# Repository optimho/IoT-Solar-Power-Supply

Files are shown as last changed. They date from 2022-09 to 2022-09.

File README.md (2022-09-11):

# IoT-Solar-Power-Supply
A small but highly efficient Solar power supply for electronics 

The repo consists of eagle cad files and a zip file with fabrication ready gerber files.

The power supply will charge a Lithium Ion 18650 battery and supply up to 4.1-3.0v 1A.
The battery voltage is monitored so that it will not run the battery flat and protect the battery. 

There is no short circuit protection on the device, so consider a 5v 1.5A fuse if you think that it is necssary.

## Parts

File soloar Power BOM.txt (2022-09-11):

Partlist exported from /home/michael/EAGLE/projects/Solar Power Supply/soloar Power.sch at 11/09/22 3:00 PM

Part Value                          Device                    Package              Description                                                   AVAILABILITY CATEGORY   CREATED_BY    DESCRIPTION                                DIGIKEY_PART_NUMBER DRAIN_CURRENT MANUFACTURER                     MF             MP               MPN               OC_FARNELL OC_NEWARK OPERATING_TEMP OPERATING_TEMPERATURE PACKAGE                PART_STATUS POPULARITY PRICE PROD_ID    PURCHASE-URL                                                      ROHS_COMPLIANCE ROHS_COMPLIANT SERIES SF_SKU    SUB-CATEGORY SUBCATEGORY    THERMALLOSS TYPE            VALUE  
BT1                                 BATTERY-18650             BATTERY_18650-HOLDER Battery - Single Cell                                                                                                                                                                                                                                                                                                                                                             BATT-12327                                                                                                         PRT-13113                                                                
C1   CC0805KRX7R9BB104              CC0805KRX7R9BB104         CAP_0805             CAP CER 0.1UF 50V X7R 0805                                                            PCBLayout.com                                            311-1140-2-ND                     Yageo                                                            CC0805KRX7R9BB104                                                           SMD 0805                                                                                                                                                                                                                                        
J1   22-27-2021-02                  22-27-2021-02             6410-02              CONNECTOR                                                                                                                                                                                                         MOLEX                                             unknown    unknown                                                                           0                                                                                                                                                                                                            
Q1   SI2301CDS-T1-GE3               PMOSFET__SOT23            SOT23                P-Channel MOSFET - Generic                                                 Transistor                                                                                                                                                                                                                                                                                                                                                                                                                          MOSFET                                  P-Channel       PMOSFET
T1                                  MMBT3904LT1-NPN-SOT23-BEC SOT23-BEC            NPN Transistror                                                                                                                                                                                                                                                                                                                                                  0                                                                                                                                                                                                            
U$1  10K                            SMD-RES-10K-1%-1/8W(0805) R0805                301012152                                                                                                                                                                                                                                         RC0805FR-0710KL                                                                                                                                                                                                                                                                                                      10K    
U$2  2828XX-4282837-4               2828XX-4282837-4          TERMBLK_508-4N       4 Position Wire to Board Terminal Block Horizontal with Board              Connector                TERM BLK 4P SIDE ENT 5.08mm PCB                                              TE Connectivity                                                  282837-4                                              40°C to +105°C                               Active                                                                                                    RoHS Compliant                 283737                        Terminal Block             Side Wire Entry        
U1   LTC4070EMS8EPBF                LTC4070EMS8EPBF           MSOP-8_MS            Check availability                                            In Stock                               Charger IC Lithium Ion/Polymer 8-MSOP-EP                                                                     Analog Devices LTC4070EMS8E#PBF                                                                             MSOP -8 Analog Devices                        None             https://pricing.snapeda.com/search/part/LTC4070EMS8E#PBF/?ref=eda                                                                                                                
X1   RS Stock No.: 151-237  10k NTC NCP18WF104J03RB           NCP18WF104J03RB      THERM NTC 100KOHM 4250K 0603                                                          PCBLayout.com                                            490-2430-2-ND                     Murata Electronics North America                                 NCP18WF104J03RB                                                             0603

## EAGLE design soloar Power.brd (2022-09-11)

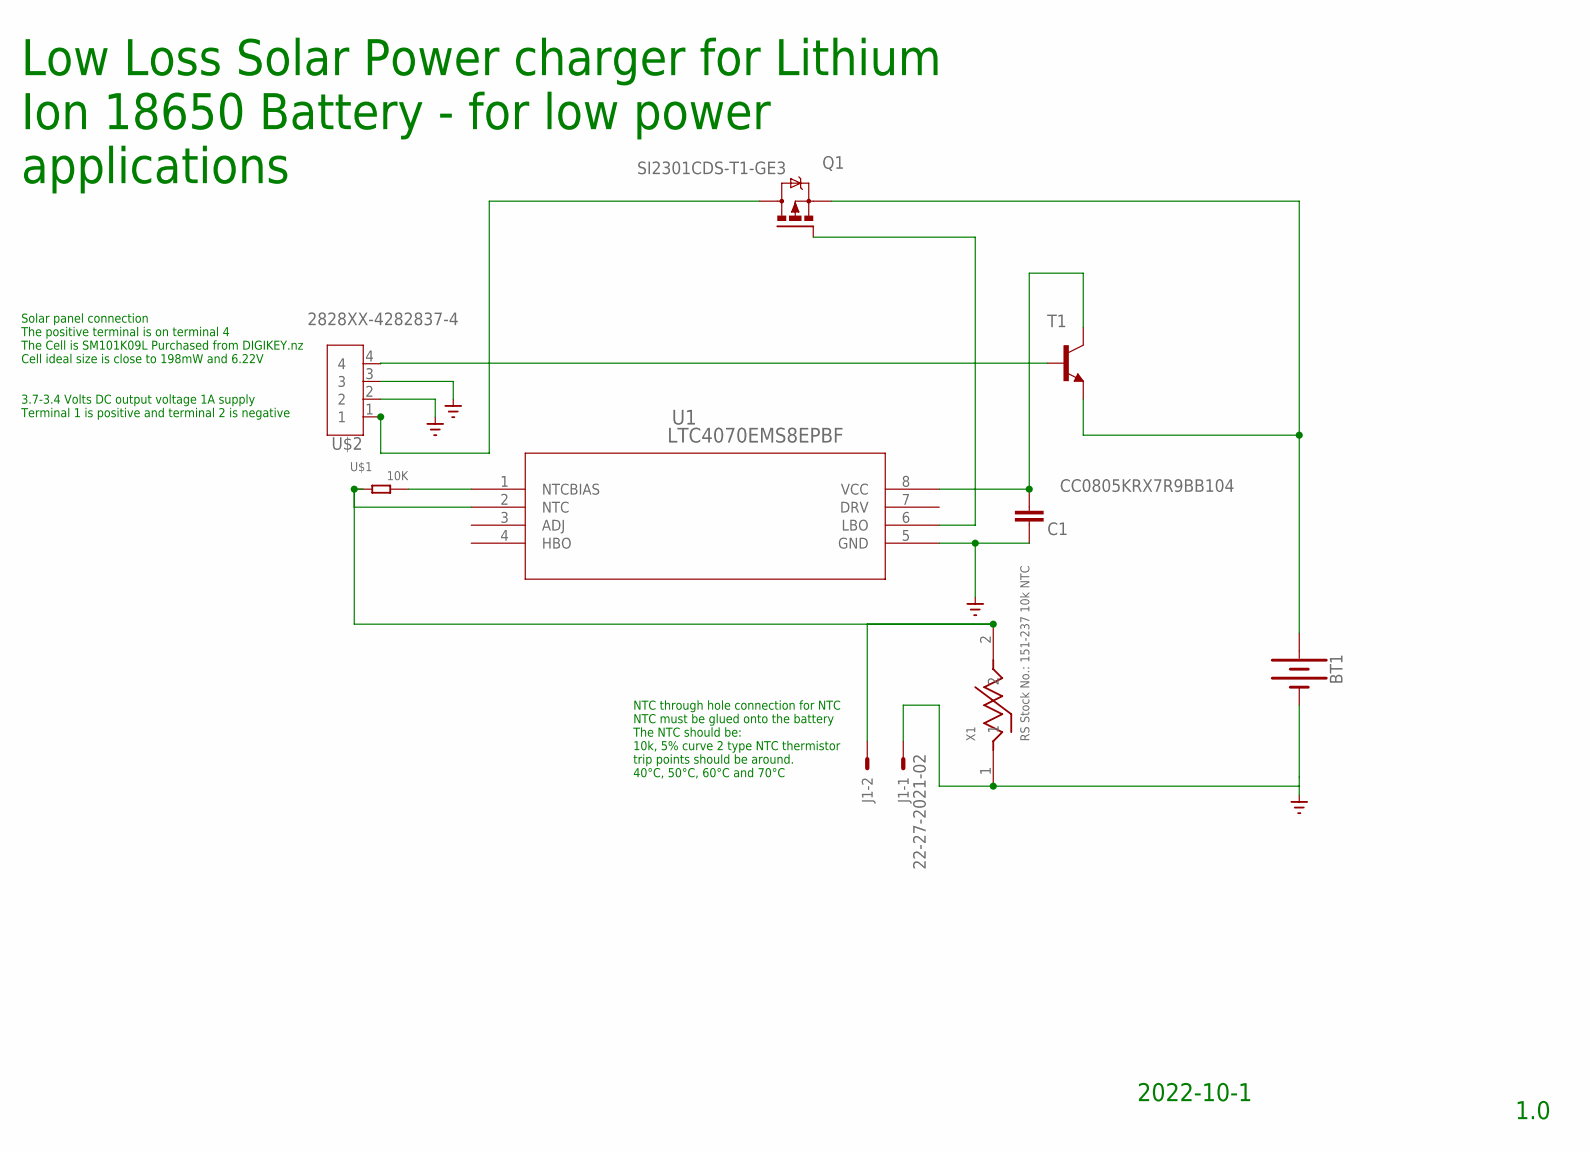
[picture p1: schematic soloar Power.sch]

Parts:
BT1: BATTERY-18650; BATTERY_18650-HOLDER
C1: CC0805KRX7R9BB104; CAP_0805
J1: 22-27-2021-02; 6410-02
Q1: SI2301CDS-T1-GE3; SOT23
T1: MMBT3904LT1-NPN-SOT23-BEC; SOT23-BEC
U1: LTC4070EMS8EPBF; MSOP-8_MS
U$1: 10K; R0805
U$2: 2828XX-4282837-4; TERMBLK_508-4N
X1: RS Stock No.: 151-237 10k NTC; NCP18WF104J03RB

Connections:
GND: BT1.GND@1 (-), C1.2, J1.1, U1.5 (GND), U$2.2, U$2.3, X1.1
unnamed: T1.B, U$2.4
unnamed: BT1.PWR@1 (+), Q1.2 (S), T1.E
unnamed: C1.1, T1.C, U1.8 (VCC)
unnamed: U1.1 (NTCBIAS), U$1.1
unnamed: Q1.3 (D), U$2.1
unnamed: J1.2, U1.2 (NTC), U$1.2, X1.2
unnamed: Q1.1 (G), U1.6 (LBO)

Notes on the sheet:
3.7-3.4 Volts DC output voltage 1A supply Terminal 1 is positive and terminal 2 is negative
Solar panel connection The positive terminal is on terminal 4 The Cell is SM101K09L Purchased from DIGIKEY.nz Cell ideal size is close to 198mW and 6.22V
NTC through hole connection for NTC NTC must be glued onto the battery The NTC should be: 10k, 5% curve 2 type NTC thermistor trip points should be around. 40°C, 50°C, 60°C and 70°C
Low Loss Solar Power charger for Lithium Ion 18650 Battery - for low power applications
2022-10-1
1.0

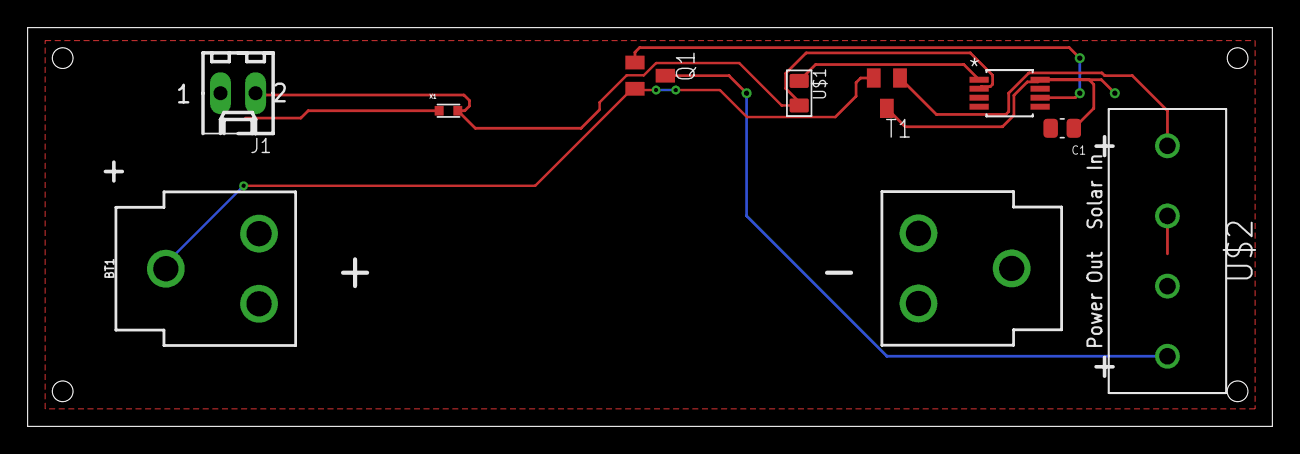
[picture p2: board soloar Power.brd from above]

Board: 2 copper layers, 90.2 x 28.9 mm, 9 parts (0 on the bottom side), 8 nets.

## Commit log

2022-09-11 Initial commit of solar power source for IOT
    [DRILEGEND.CFG, soloar Power.brd, soloar Power.sch]
2022-09-11 Add BOM

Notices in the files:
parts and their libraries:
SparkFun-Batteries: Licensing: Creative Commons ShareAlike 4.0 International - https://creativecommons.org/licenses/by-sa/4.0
